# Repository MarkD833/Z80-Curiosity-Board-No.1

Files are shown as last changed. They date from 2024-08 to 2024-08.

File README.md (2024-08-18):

# Zilog Z80 Curiosity Board #1

I've recently had time to go back to my youth and re-discover some of the microprocessors that were available at the time. This is my first Z80 board. I wanted to put together a small board that had a Z80 as well as PIO (parallel I/O), SIO (serial I/O) and CTC (Counter Timer) chips.

I chose to use PLCC devices to try and keep the board size small enough to keep the costs down at JLCPCB. That decision proved to be a problem as I thought I'd sourced some SIO/2 chips in PLCC44 packaging. Unfortunately my source let me down and I decided to go with an SC16C2554 DUART instead.

## Description

The aim of this project is to see if I can build my own Z80 based system to experiment on. As well as the Z80 processor (Z84C0020VEC), it will have some parallel I/O (Z84C2010VEG), serial I/O (SC16C2554) and some counter timers (Z84C3010VEC) . I also wanted to see if I could port CP/M to this hardware as an additional challenge, so the design would need a CompactFlash card interface. My starting point for CP/M was Grant Searles excellent [web page](http://searle.x10host.com/cpm/index.html).

## Design

The design is fairly straightforward, using a skinny 64Kb SRAM from my stash as well as a 64Kb EEPROM for non volatile storage.

I studied other designs that I came across and liked a concept that I came across whereby on startup, the whole of the ROM was copied into RAM and then the ROM disabled. The hardware was configured so that the ROM and the RAM both occupied the same 64Kb, but initially any read accessed would go to the ROM and any write accesses would go to the RAM. Once the ROM was copied into RAM (at the same addresses), the ROM would be disabled giving full read/write access to the RAM and the Z80 would continue to execute instructions as if nothing had happened.

The design uses simple logic chips to handle the address decoding, as well as the disabling of the ROM etc.

# The board layout

This is an annotated 3D view of the board generated by Kicad as it stands at v1.1.

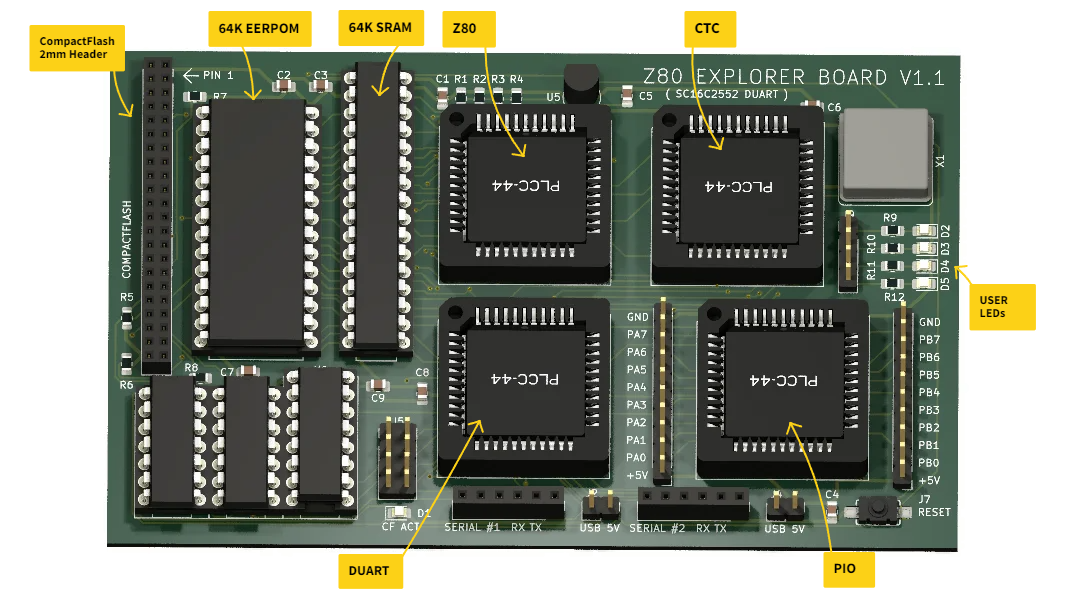
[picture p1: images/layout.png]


# Software

I adapted Dave Dunfields MONZ80 monitor program to work with this board. MONZ80 can be found on [Dave's website](https://dunfield.themindfactory.com/dnldsrc.htm) as part of the MONITORS.ZIP file. There is no documentation for the monitor but most of the commands are self explanatory.

The monitor code needs tweeking to support the specific UART hardware I am using but that simply involves providing code to initialise the UART and code to output a characher/byte as well as read in a character/byte. My modified version of MONZ80 is in the code folder and has been edited to allow assembly using the free online assembler at [ASM80.COM](https://asm80.com) - select the Z80 CPU.

# Known errors

* The initial design messed up the addressing of the DUART chip such that only one serial port was available. Cutting a few tracks and adding a few jumper wires sorted that error out. The changes are detailed on the Kicad schematic.

* The choice of the SC16C2554 DUART meant that I couldn't use IM2 for interrupts. The initial code for the interrupt handlers had to be at the start of memory - just where CP/M also needed to store information. 

# Conclusions

The board works, but sadly not how I had hoped due to the interrupt issue mentioned above.

It is possible to run CP/M on this board once the files are loaded onto the CompactFlash card. That is where the issue lies. It is possible to follow Grant Searles instructions on transferring files onto the CF card using the DOWNLOAD command and the packaging tool, but in order to do so, there needs to be pauses between lines and between characters when sending the files over as there is no way for the CP/M system to use an interrupt driven serial handler to buffer the data.

## License

This project is licensed under the GNU General Public License v3.0 - see the LICENSE.md file for details

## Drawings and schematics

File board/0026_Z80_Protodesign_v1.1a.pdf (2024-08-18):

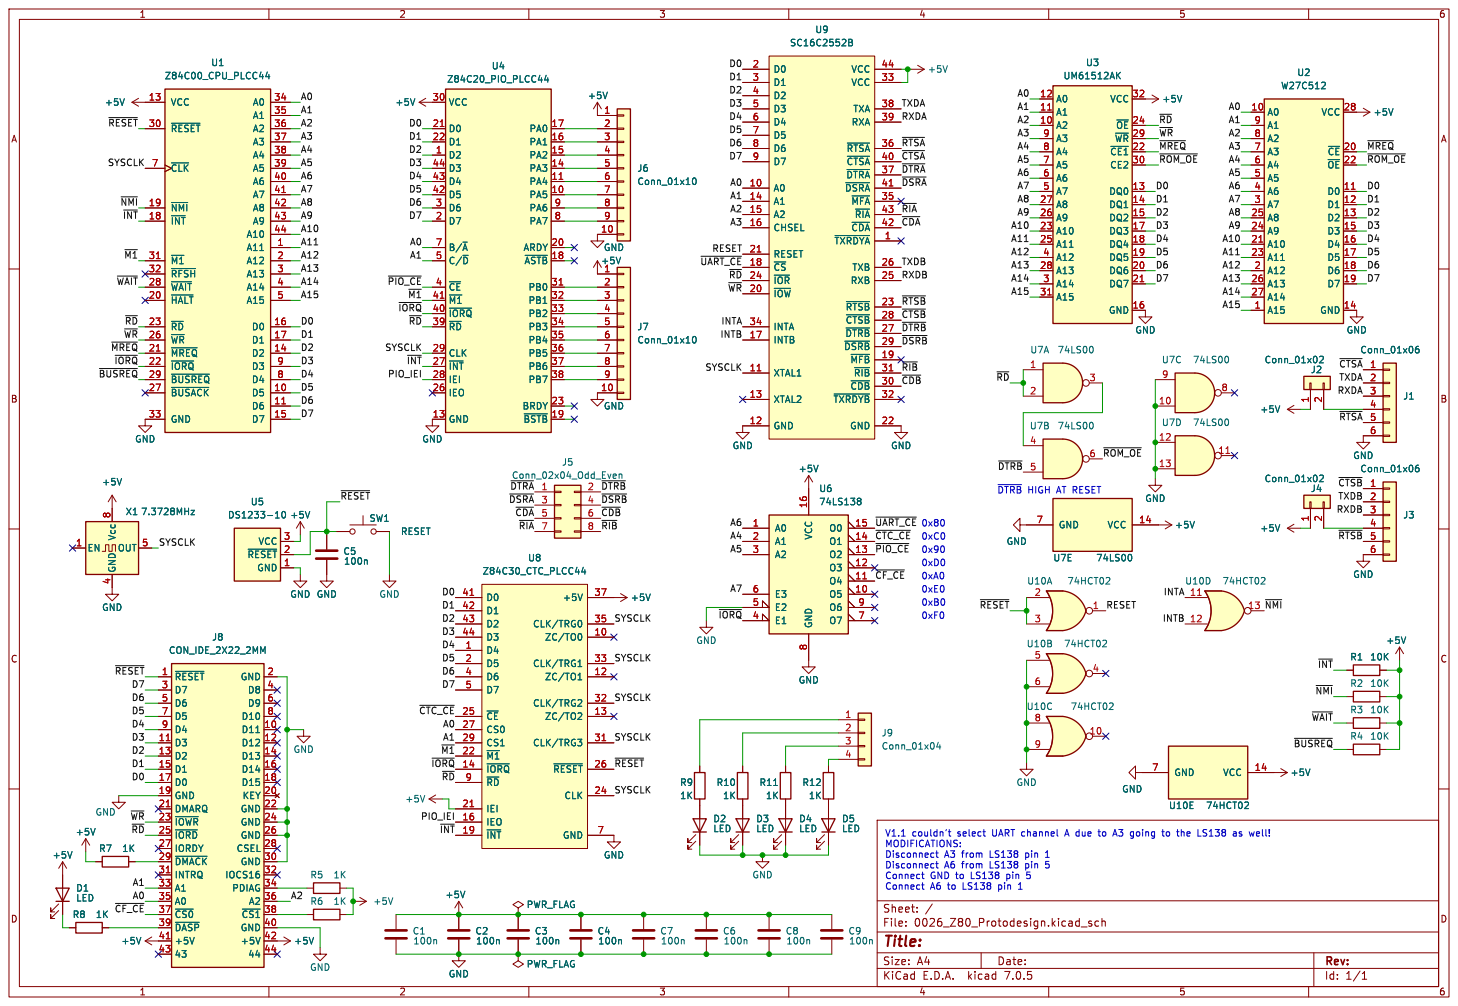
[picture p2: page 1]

4 OUT 5 Vcc 8 U4 Z84C20_PIO_PLCC44 D2 1 PA5 10 PA4 11 GND 13 PA3 14 PA2 15 PA1 16 PA0 17 ~{ASTB} 18 ~{BSTB} 19 D7 2 ARDY 20 D0 21 D1 22 BRDY 23

Id: 1/1 Title: File: 0026_Z80_Protodesign.kicad_sch Sheet: / GND

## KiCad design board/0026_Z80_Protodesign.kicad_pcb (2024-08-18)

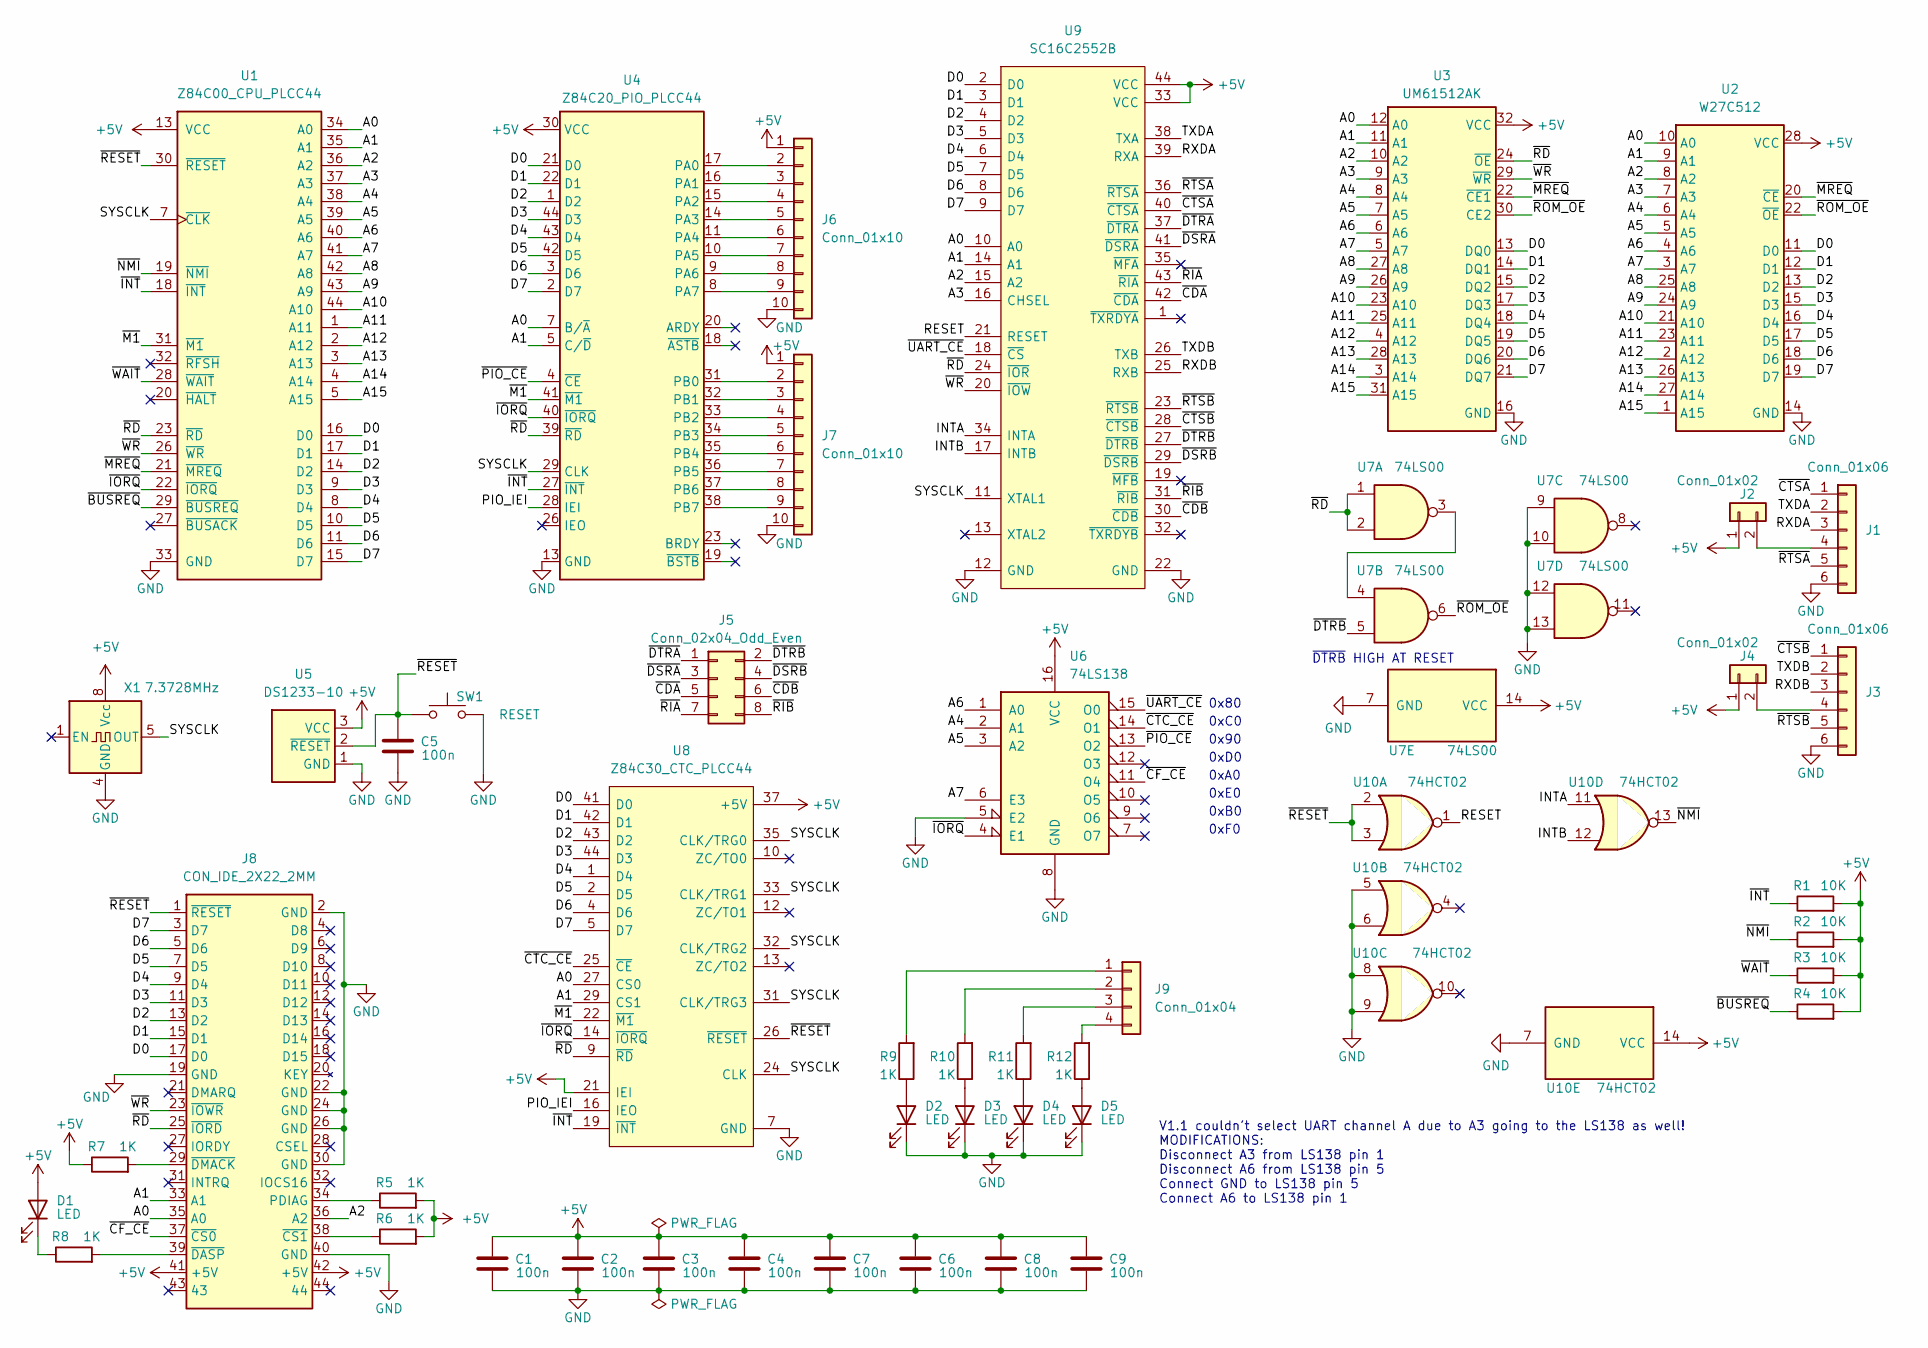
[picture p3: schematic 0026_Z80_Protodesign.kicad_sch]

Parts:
C1, C2, C3, C4, C5, C6, C7, C8, C9: 100n; C_0805_2012Metric_Pad1.18x1.45mm_HandSolder
D1, D2, D3, D4, D5: LED; LED_0805_2012Metric_Pad1.15x1.40mm_HandSolder
J1, J3: Conn_01x06; PinHeader_1x06_P2.54mm_Vertical
J2, J4: Conn_01x02; PinHeader_1x02_P2.54mm_Vertical
J5: Conn_02x04_Odd_Even; PinHeader_2x04_P2.54mm_Vertical
J6, J7: Conn_01x10; PinHeader_1x10_P2.54mm_Vertical
J8: CON_IDE_2X22_2MM; CompactFlashHeader_2x22_P2.00mm_Vertical
J9: Conn_01x04; PinHeader_1x04_P2.54mm_Vertical
R1, R2, R3, R4: 10K; R_0805_2012Metric_Pad1.20x1.40mm_HandSolder
R5, R6, R7, R8, R9, R10, R11, R12: 1K; R_0805_2012Metric_Pad1.20x1.40mm_HandSolder
SW1: RESET; TACTILE_SWITCH_SMD_6.0X3.5MM
U1: Z84C00_CPU_PLCC44; PLCC-44_THT-Socket
U2: W27C512; DIP-28_W15.24mm
U3: UM61512AK; DIP-32_W7.62mm
U4: Z84C20_PIO_PLCC44; PLCC-44_THT-Socket
U5: DS1233-10; TO-92L_Inline
U6: 74LS138; DIP-16_W7.62mm_Socket
U7: 74LS00; DIP-14_W7.62mm_Socket
U8: Z84C30_CTC_PLCC44; PLCC-44_THT-Socket; Manufacturer_Part_Number Z84C3010PEG
U9: SC16C2552B; PLCC-44_THT-Socket
U10: 74HCT02; DIP-14_W7.62mm_Socket
X1: 7.3728MHz; Oscillator_DIP-8

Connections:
+5V: C1.2, C2.2, C3.2, C4.2, C6.2, C7.2, C8.2, C9.2, D1.2 (A), J2.1, J4.1, J6.1, J7.1, J8.41 (+5V), J8.42 (+5V), R1.2, R2.2, R3.2, R4.2, R5.2, R6.2, R7.1, U1.13 (VCC), U2.28 (VCC), U3.32 (VCC), U4.30 (VCC), U5.3 (VCC), U6.16 (VCC), U7.14 (VCC), U8.21 (IEI), U8.37 (+5V), U9.33 (VCC), U9.44 (VCC), U10.14 (VCC), X1.8 (Vcc)
/A0: J8.35 (A0), U1.34 (A0), U2.10 (A0), U3.12 (A0), U4.7 (B/~A), U8.27 (CS0), U9.10 (A0)
/A1: J8.33 (A1), U1.35 (A1), U2.9 (A1), U3.11 (A1), U4.5 (C/~D), U8.29 (CS1), U9.14 (A1)
/A2: J8.36 (A2), U1.36 (A2), U2.8 (A2), U3.10 (A2), U9.15 (A2)
/A4: U1.38 (A4), U2.6 (A4), U3.8 (A4), U6.2 (A1)
/A5: U1.39 (A5), U2.5 (A5), U3.7 (A5), U6.3 (A2)
/A7: U1.41 (A7), U2.3 (A7), U3.5 (A7), U6.6 (E3)
/A8: U1.42 (A8), U2.25 (A8), U3.27 (A8)
/A9: U1.43 (A9), U2.24 (A9), U3.26 (A9)
/A10: U1.44 (A10), U2.21 (A10), U3.23 (A10)
/A11: U1.1 (A11), U2.23 (A11), U3.25 (A11)
/A12: U1.2 (A12), U2.2 (A12), U3.4 (A12)
/A13: U1.3 (A13), U2.26 (A13), U3.28 (A13)
/A14: U1.4 (A14), U2.27 (A14), U3.3 (A14)
/A15: U1.5 (A15), U2.1 (A15), U3.31 (A15)
/D0: J8.17 (D0), U1.16 (D0), U2.11 (D0), U3.13 (DQ0), U4.21 (D0), U8.41 (D0), U9.2 (D0)
/D1: J8.15 (D1), U1.17 (D1), U2.12 (D1), U3.14 (DQ1), U4.22 (D1), U8.42 (D1), U9.3 (D1)
/D2: J8.13 (D2), U1.14 (D2), U2.13 (D2), U3.15 (DQ2), U4.1 (D2), U8.43 (D2), U9.4 (D2)
/D3: J8.11 (D3), U1.9 (D3), U2.15 (D3), U3.17 (DQ3), U4.44 (D3), U8.44 (D3), U9.5 (D3)
/D4: J8.9 (D4), U1.8 (D4), U2.16 (D4), U3.18 (DQ4), U4.43 (D4), U8.1 (D4), U9.6 (D4)
/D5: J8.7 (D5), U1.10 (D5), U2.17 (D5), U3.19 (DQ5), U4.42 (D5), U8.2 (D5), U9.7 (D5)
/D6: J8.5 (D6), U1.11 (D6), U2.18 (D6), U3.20 (DQ6), U4.3 (D6), U8.4 (D6), U9.8 (D6)
/D7: J8.3 (D7), U1.15 (D7), U2.19 (D7), U3.21 (DQ7), U4.2 (D7), U8.5 (D7), U9.9 (D7)
/INTA: U9.34 (INTA), U10.11
/INTB: U9.17 (INTB), U10.12
/PIO_IEI: U4.28 (IEI), U8.16 (IEO)
/RESET: U9.21 (RESET), U10.1
/RXDA: J1.3, U9.39 (RXA)
/RXDB: J3.3, U9.25 (RXB)
/SYSCLK: U1.7 (~CLK), U4.29 (CLK), U8.24 (CLK), U8.31 (CLK/TRG3), U8.32 (CLK/TRG2), U8.33 (CLK/TRG1), U8.35 (CLK/TRG0), U9.11 (XTAL1), X1.5 (OUT)
/TXDA: J1.2, U9.38 (TXA)
/TXDB: J3.2, U9.26 (TXB)
/~BUSREQ: R4.1, U1.29 (~BUSREQ)
/~CDA: J5.5, U9.42 (~CDA)
/~CDB: J5.6, U9.30 (~CDB)
/~CF_CE: J8.37 (~CS0), U6.11 (O4)
/~CTC_CE: U6.14 (O1), U8.25 (~CE)
/~CTSA: J1.1, U9.40 (~CTSA)
/~CTSB: J3.1, U9.28 (~CTSB)
/~DSRA: J5.3, U9.41 (~DSRA)
/~DSRB: J5.4, U9.29 (~DSRB)
/~DTRA: J5.1, U9.37 (~DTRA)
/~DTRB: J5.2, U7.5, U9.27 (~DTRB)
/~INT: R1.1, U1.18 (~INT), U4.27 (~INT), U8.19 (~INT)
/~IORQ: U1.22 (~IORQ), U4.40 (~IORQ), U6.4 (E1), U8.14 (~IORQ)
/~M1: U1.31 (~M1), U4.41 (~M1), U8.22 (~M1)
/~MREQ: U1.21 (~MREQ), U2.20 (~CE), U3.22 (~CE1)
/~NMI: R2.1, U1.19 (~NMI), U10.13
/~PIO_CE: U4.4 (~CE), U6.13 (O2)
/~RD: J8.25 (~IORD), U1.23 (~RD), U3.24 (~OE), U4.39 (~RD), U7.1, U7.2, U8.9 (~RD), U9.24 (~IOR)
/~RESET: C5.2, J8.1 (~RESET), SW1.1, U1.30 (~RESET), U5.2 (~RESET), U8.26 (~RESET), U10.2, U10.3
/~RIA: J5.7, U9.43 (~RIA)
/~RIB: J5.8, U9.31 (~RIB)
/~ROM_OE: U2.22 (~OE), U3.30 (CE2), U7.6
/~RTSA: J1.5, U9.36 (~RTSA)
/~RTSB: J3.5, U9.23 (~RTSB)
/~UART_CE: U6.15 (O0), U9.18 (~CS)
/~WAIT: R3.1, U1.28 (~WAIT)
/~WR: J8.23 (~IOWR), U1.26 (~WR), U3.29 (~WR), U9.20 (~IOW)
unnamed: D1.1 (K), R8.1
unnamed: D2.2 (A), R9.1
unnamed: D3.2 (A), R10.1
unnamed: D4.2 (A), R11.1
unnamed: D5.2 (A), R12.1
unnamed: J1.4, J2.2
unnamed: J3.4, J4.2
unnamed: J6.2, U4.17 (PA0)
unnamed: J6.3, U4.16 (PA1)
unnamed: J6.4, U4.15 (PA2)
unnamed: J6.5, U4.14 (PA3)
unnamed: J6.6, U4.11 (PA4)
unnamed: J6.7, U4.10 (PA5)
unnamed: J6.8, U4.9 (PA6)
unnamed: J6.9, U4.8 (PA7)
unnamed: J7.2, U4.31 (PB0)
unnamed: J7.3, U4.32 (PB1)
unnamed: J7.4, U4.33 (PB2)
unnamed: J7.5, U4.34 (PB3)
unnamed: J7.6, U4.35 (PB4)
unnamed: J7.7, U4.36 (PB5)
unnamed: J7.8, U4.37 (PB6)
unnamed: J7.9, U4.38 (PB7)
unnamed: J8.34 (PDIAG), R5.1
unnamed: J8.38 (~CS1), R6.1
unnamed: J8.39 (~DASP), R8.2
unnamed: J8.29 (~DMACK), R7.2
unnamed: J9.1, R9.2
unnamed: J9.2, R10.2
unnamed: J9.3, R11.2
unnamed: J9.4, R12.2
unnamed: U7.3, U7.4

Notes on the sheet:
0xC0
0x80
0xE0
0xA0
0xD0
V1.1 couldn't select UART channel A due to A3 going to the LS138 as well! MODIFICATIONS: Disconnect A3 from LS138 pin 1 Disconnect A6 from LS138 pin 5 Connect GND to LS138 pin 5 Connect A6 to LS138 pin 1
0xB0
0xF0
~{DTRB} HIGH AT RESET
0x90

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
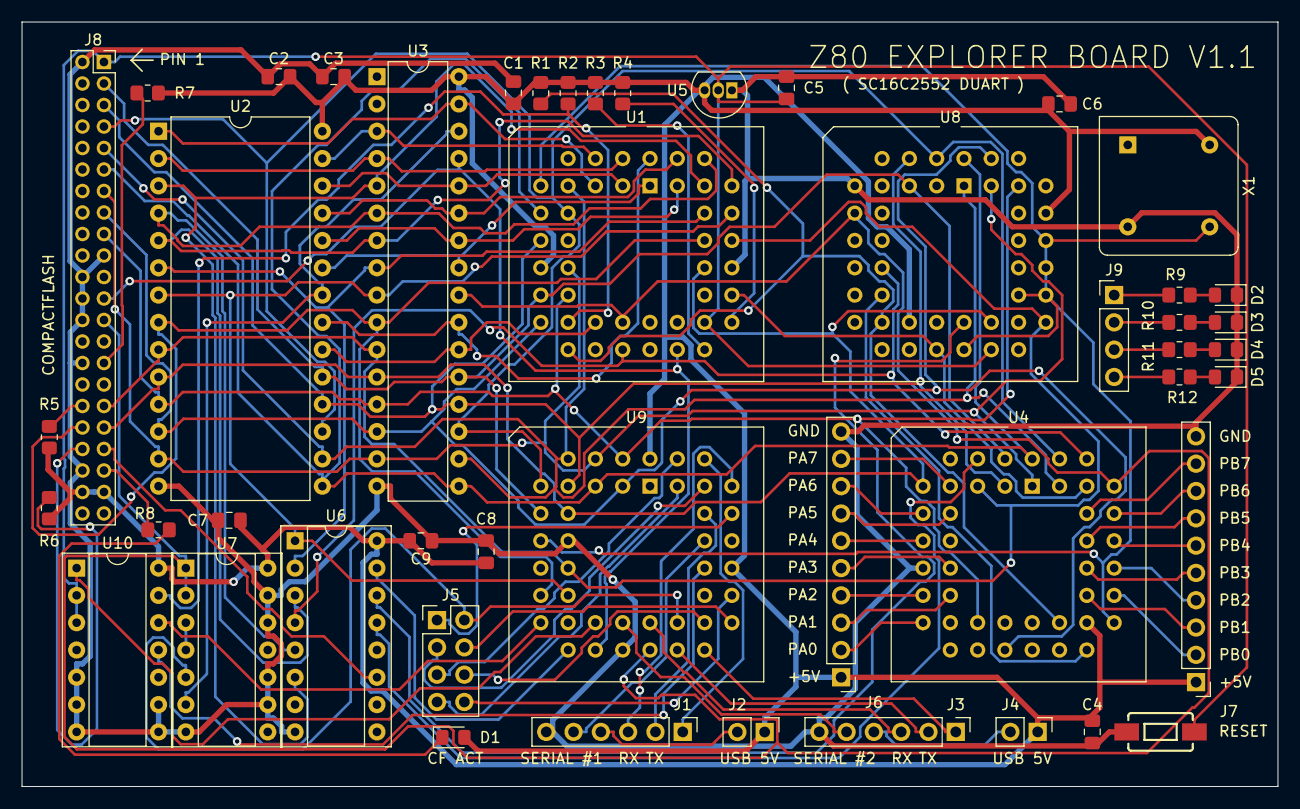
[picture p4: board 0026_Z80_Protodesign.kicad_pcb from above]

Board: 2 copper layers, 116.8 x 71.1 mm, 47 parts (0 on the bottom side), 94 nets.

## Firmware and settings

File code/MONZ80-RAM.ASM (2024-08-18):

;
; MONZ80: A software debugger for the Z80 processor
;
; ?COPY.TXT 1996-2007 Dave Dunfield
; **See COPY.TXT**.
;
;------------------------------------------------------------------------------
; 2024-03-17 Modified by Mark Durham for the ASM80.COM online assembler and to
; support my Z80 pathfinder board using an SC16C2552B DUART.
;
; Initially ROM is $0000-$FFFF (read only) and RAM is $0000-$FFFF (write only)
; IOINIT copies ROM to RAM and disables ROM leaving full 64K of RAM available.
;------------------------------------------------------------------------------
; SC16C2552B Baud rates
; with a 7.3728MHz clock, divisor for 9600 baud is 7372800 / 9600 / 16 = 48
BD_9600		EQU	48
BD_19200	EQU	24
BD_38400	EQU	12
BD_57600	EQU	8
BD_115200	EQU	4

; Set BAUD to one of the definitions above
BAUD	EQU	BD_57600

;
; Monitor data
;
MCODE   EQU $0000       ;Monitor CODE goes here
MDATA   EQU $1FA0       ;Monitor DATA goes here
UCODE   EQU $2000	   ;User CODE address
USTACK  EQU $FFFF	   ;User STACK address (default)
;
	ORG MDATA

; User registers (saved while monitor active)
uAF		DS	2	   ;User AF register
uBC		DS	2	   ;User BC register
uDE		DS	2	   ;User DE register
uHL		DS	2	   ;User HL register
uIX		DS	2	   ;User IX register
uIY		DS	2	   ;User IY register
uPC		DS	2	   ;User PC register
uSP		DS	2	   ;User SP register

; I/O control byte:
;  7/80 = Output paused
;  6/40 = Echo input
;  5/20 = Convert to upper case
;  4/10 = Clear input stream first
IOCTL:	DS	1		;I/O control byte
BRKTAB:	DS	8*3		;Breakpoint table
TEMP:	DS	2		;Temporary storage
TEMP1:	DS	1		;Temporary storage
TEMP2:	DS	1		;Temporary storage
BUFFER:	DS	50		;Disassembler output buffer

MONSTK:		;Some free space

; MD Create high and low byte of BRKTAB address as ASM80 doesn't understand = directive
; Original code had code like: LD  D,=BRKTAB which apparently means load D reg with
; the upper 8 bits of BRKTAB
BRKTAB_H    EQU     BRKTAB/256
BRKTAB_L    EQU     BRKTAB#256
;
; Monitor Code
;
	ORG MCODE
;
	JP  BEGIN	   ;Start up monitor
	ORG 1*8	 ;RST 1
	JP  UCODE+(1*8) ;Execute user code
	ORG 2*8	 ;RST 2
	JP  UCODE+(2*8) ;Execute user code
	ORG 3*8	 ;RST 3
	JP  UCODE+(3*8) ;Execute user code
	ORG 4*8	 ;RST 4
	JP  UCODE+(4*8) ;Execute user code
	ORG 5*8	 ;RST 5
	JP  UCODE+(5*8) ;Execute user code
	ORG 6*8	 ;RST 6
	JP  UCODE+(6*8) ;Execute user code
	ORG 7*8	 ;RST 7 - Breakpoint
;
; Breakpoint encountered - save registers, replace breakpoints
;
BRKPT:
	LD  (uHL),HL	;Save HL
	POP HL	  ;Get PC
	DEC HL	  ;Backup to RST instruction
	LD  (uPC),HL	;Save PC
BRKP1:
	PUSH	AF	  ;Get AF
	POP HL	  ;Copy
	LD  (uAF),HL	;Save AF
	LD  HL,0		;Get 0
	ADD HL,SP	   ;Get SP
	LD  (uSP),HL	;Save SP
	EX  DE,HL	   ;Get DE
	LD  (uDE),HL	;Save DE
	LD  H,B	 ;Get B
	LD  L,C	 ;Get C
	LD  (uBC),HL	;Save BC
	LD  (uIX),IX	;Save IX
	LD  (uIY),IY	;Save IY
; Remove any active breakpoints
	LD  HL,BRKTAB   ;Point to breakpoint table
	LD  B,8	 ;Total of 8 breakpoints
rembrk1:
	LD  E,(HL)	  ;Get LOW address
	INC HL	  ;Skip to next
	LD  D,(HL)	  ;Get HIGH address
	INC HL	  ;Skip to next
	LD  A,D	 ;Get HIGH
	OR  L	   ;Test with LOW
	JR  Z,rembrk2   ;No breakpoint here
	LD  A,(HL)	  ;Get opcode
	LD  (DE),A	  ;Resave opcode value
rembrk2:
	INC HL	  ;Skip to next
	DJNZ	rembrk1	 ;Remove them all
	CALL	RDUMP	   ;Display registers
	JR  ENTMON	  ;Enter monitor
	
;------------------------------------------------------------------------------
; Cold start entry point
;------------------------------------------------------------------------------
BEGIN:
	JP		IOINIT	  ;Copy ROM to RAM & initialize I/O
IOINIT_RET:
	LD  SP,MONSTK   ;Set initial stack
; Initialize monitor memory to zero
	LD  HL,MDATA	;Point to start of monitor RAM
	LD  DE,TEMP	 ;End of initialized area
begin1:
	LD  (HL),0	  ;Zero 1 byte
	CALL	CHLDE	   ;Perform compare
	INC HL	  ;Advance
	JR  C,begin1	;Zero it all
; Output welcome message
	CALL	WRMSG	   ;Output message
	DB  $0A,$0D
	DB 'MONZ80 Version 1.0'
	DB  $0A,$0D,$0A
	DB '?COPY.TXT 1996-2007 Dave Dunfield'
	DB  $0A,$0D
	DB '**See COPY.TXT**.'
	DB  $0A,0
; Set initial PC and SP
	LD  HL,UCODE	;Get default PC
	LD  (uPC),HL	;Set it
	LD  HL,USTACK   ;Get default SP
	LD  (uSP),HL	;Set it
; Warm-start of monitor
ENTMON:
	LD  SP,MONSTK   ;Reset SP
	LD  A,%01100000 ;Echo, Ucase
	LD  (IOCTL),A   ;Set I/O control
	CALL	WRMSG	   ;Output string
	DB  $0A,$0D,'>',0   ;Prompt string
; Get command from console
	LD  C,0	 ;Clear first char
	LD  D,C	 ;Clear pending flag
cmd:
	LD  B,C	 ;Set first character
	CALL	GETC		;Get command character
	LD  C,A	 ;Set second character
; Search for command in command table
	LD  HL,CTABLE   ;Point to command table
cmd1:
	LD  A,C	 ;Get LAST char
	CP  (HL)		;Match?
	INC HL	  ;Skip to next
	JR  NZ,cmd2	 ;No, try next
	LD  A,B	 ;Get HIGH char
	CP  (HL)		;Match?
	JR  NZ,cmd2	 ;No, try next
; We found the command - execute handler
	INC HL	  ;Skip second
	CALL	SPACE	   ;Separator
	LD  A,(HL)	  ;Get LOW address
	INC HL	  ;Advance
	LD  H,(HL)	  ;Get HIGH address
	LD  L,A	 ;Set LOW address
	LD  BC,CMDRET   ;Get return address
	PUSH	BC	  ;Save for return
	JP  (HL)		;Execute
; This command didn't match, check for part of two char sequence
cmd2:	LD  A,C	 ;Get char
	CP  (HL)		;Does it match leading of 2char?
	JR  NZ,cmd3	 ;No, skip it
	INC D	   ;Record possibility
; Advance to next table entry
cmd3:
	INC HL	  ;Skip second
	INC HL	  ;Skip address LOW
	INC HL	  ;Skip address HIGH
	LD  A,(HL)	  ;Get character
	AND A	   ;End of table
	JR  NZ,cmd1	 ;Check every entry
	OR  B	   ;First time through?
	JR  NZ,ERROR	;No, report error
	OR  D	   ;Possible 2 char?
	JR  NZ,CMD	  ;Try again
; An error has occured
ERROR:
	CALL	WRMSG	   ;Output message
	DB	' ?',0		;Error message
CMDRET:
	LD  A,(IOCTL)   ;Get I/O control
	AND %00010000   ;Clean input?
	JR  Z,entmon	;No, leave it
; Wait for serial data to clear
CLRSER:
	LD  BC,0		;Reset counter
clrse1:
	CALL	TESTC	   ;Wait for input
	AND A	   ;Character ready?
	JR  NZ,CLRSER   ;Yes, reset
	DEC BC	  ;Reduce count
	LD  A,B	 ;Get high
	OR  C	   ;Test for zero
	JR  NZ,clrse1   ;Wait for expiry
	JR  ENTMON	  ;Re-enter monitor
	
;------------------------------------------------------------------------------
; Command handler table
; MD The original assembler treated "DM" as a 16-bit word and stored it as "MD"
; All 2 character commands have their characters swapped to reflect this!
; All 1 character commands are followed by a NULL. 
;------------------------------------------------------------------------------
CTABLE:
	DB  'MD'
	DW	DUMP   ;Dump memory
	
	DB  'ID'
	DW	DISCMD ;Disassemble memory

	DB  'RD'
	DW	RDUMP  ;Dump registers

	DB  'BD'
	DW	BDUMP  ;Dump breakpoints

	DB  'RB'
	DW	SETBRK ;Set breakpoint

	DB  'E',0
	DW	EDIT	;Edit memory

	DB  'F',0
	DW	FILL	;Fill memory

	DB  'I',0
	DW	INPORT  ;Input from a port

	DB  'O',0
	DW	OUTPORT ;Output to a port

	DB  'G',0
	DW	GO	  ;Go (execute)

	DB  'T',0
	DW	STEP	;Single-step

	DB  'L',0
	DW	LOAD	;Load HEX file
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
